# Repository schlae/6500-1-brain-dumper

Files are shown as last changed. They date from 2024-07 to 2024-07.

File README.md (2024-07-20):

# 6500/1 Brain Dumper

Do you have a 6500/1 microcontroller made by MOS, Rockwell, or NCR? (and possibly others)
Do you want to dump the contents of the ROM? Here's a board for you!

This design is derived from work by Jim Brain documented [here](https://e4aws.silverdr.com/hacks/6500_1/)
with design files [here](https://github.com/Project-64/reloaded/tree/master/1520/extraction).

The original design was built on a breadboard. I've turned this into a simple PC board to save
you the effort of wiring it up. Along the way, I ported the code to another MCU (ATmega644) mostly
because that is what I had. I also edited the code to make it slightly more reliable by putting out
more clock cycles while RESET# is held low. (Although it is still not perfect and it usually takes
several tries to get a good dump.)

[Schematic](6500Dumper.pdf)

[Bill of Materials](6500Dumper.csv)

## Fabrication

I have not included the fab files because I haven't fabbed out and tested this board yet. Do this
at your own risk from the KiCad source files.

## Firmware

Build the firmware using the `make` command, assuming you have `avr-gcc` and all that installed.
I like to use the TL866 programmer with the `minipro` Linux software to program the ATmega.

Make sure to set the configuration fuses as follows:

* fuses\_lo = 0xff
* fuses\_hi = 0xd9
* fuses\_ext = 0xfd
* lock = 0xff

## Usage

The device works by putting the 6500/1 into test mode by applying 10V to the RESET# input. It
then bootstraps a small program into the MCU's RAM which copies the contents of the internal
ROM out through an I/O port, which the ATmega can read and route through its serial port to
the host.

After building up the board, connect a serial cable such as FTDI or a [module](https://www.sparkfun.com/products/15096).
Make sure it is configured for 5V operation! On the modules this is a little jumper or
PCB trace you have to cut and solder.

Connect an oscilloscope to the TARGET RESET test point on one channel (set to trigger on the
rising edge) and another channel to the PC1 test point (header pin 2 on J6). This will let
you tell if the 6500/1 has entered test mode and is putting out data.

Connect a 5V bench supply to the +5V and GND test points. Connect an *adjustable* bench supply
to the +10V input and GND. Set the current limit on this supply to something less than 100mA
to help prevent damage the chip under test, just in case.

If this is your first time using the board, you may want to power it up without the 6500/1
in the socket just to verify that the RESET# output behaves correctly. See the waveforms
below.

Put the 6500/1 chip into the J1 socket, and turn on the power. On the oscilloscope, you should
see the RESET# line go up to 10V, then back down to 5V, and you should see a row of pulses
on PC1. If you don't, examine the magnitude of the pulses on PC1 that occur *while RESET# is
at 10V*. Pulses that appear stunted or at around 2.5V mean that there is output contention
and the 6500/1 is not in test mode. 

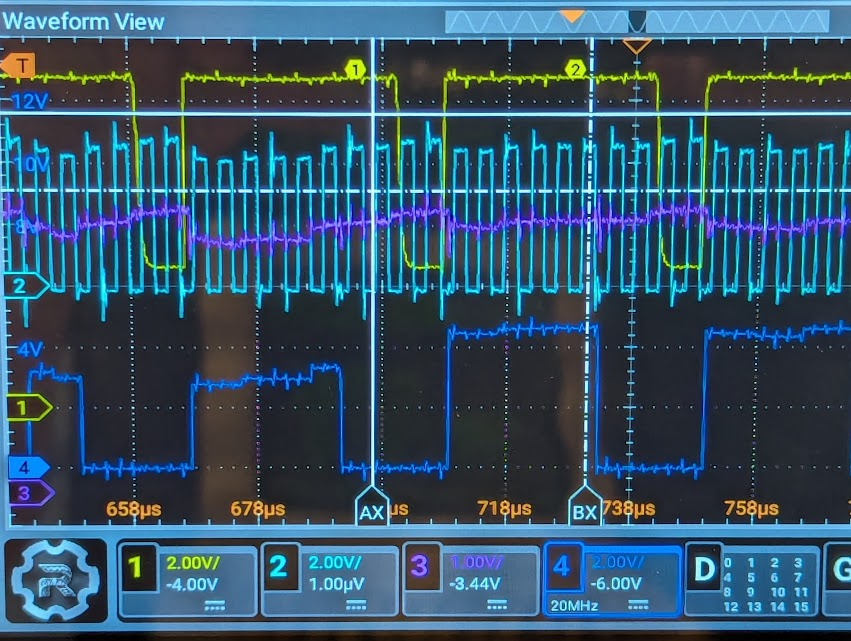
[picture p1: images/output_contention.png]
Scope shot showing output contention on PC1

**Note that CH4 (PC1) has two stunted pulses caused by output contention. CH1=reset and CH2=clock**

You might have to increase the +10V rail (but keep it below
12V or so) and then hit the reset button on the upper left to try again. It may take several tries.

If all goes well, you should see a regular set of pulses on PC1, something like this:

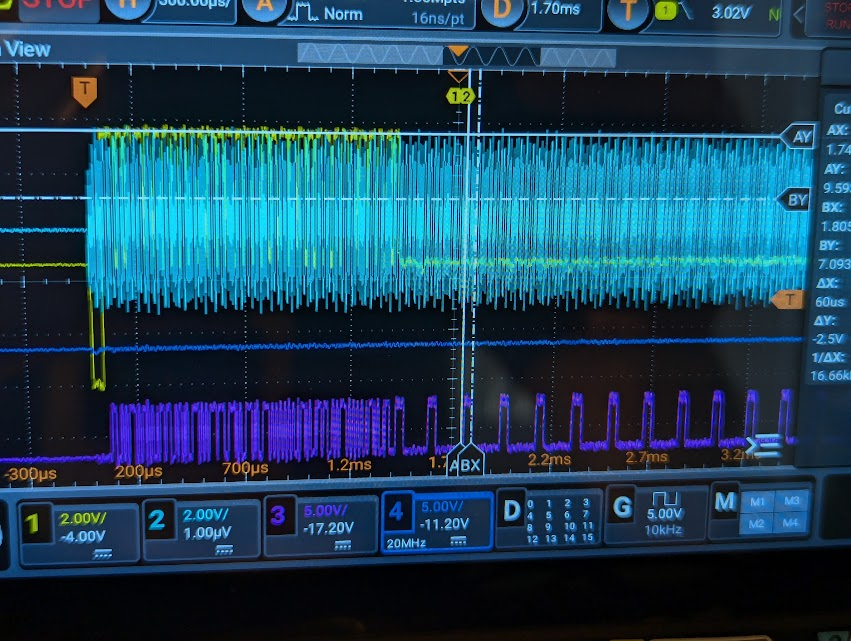
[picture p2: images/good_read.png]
Regular pulses on PC1 when RESET is at 5V, not 10V

**CH4 (PC1) shows regular pulses after RESET# falls to 5V.**

If that is the case, binary data will be transmitted from the ATmega at 57600 baud, 8N1.
This represents the binary data read back from the 6500/1's ROM (located at address
0x800 to 0xfff). I've provided a terrible Python program, `ser_read.py` to save that to
a file. You'll want to edit it to change the filename, serial port, etc (I told you
it's bad!)

## Licensing

This program is free software; you can redistribute it and/or modify
it under the terms of the GNU General Public License as published by
the Free Software Foundation; either version 2 of the License, or
(at your option) any later version.

This program is distributed in the hope that it will be useful,
but WITHOUT ANY WARRANTY; without even the implied warranty of
MERCHANTABILITY or FITNESS FOR A PARTICULAR PURPOSE.  See the
GNU General Public License for more details.

You should have received a copy of the GNU General Public License
along with this program; if not, write to the Free Software
Foundation, Inc., 59 Temple Place, Suite 330, Boston, MA  02111-1307  USA

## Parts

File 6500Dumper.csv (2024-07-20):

Item | Qty | Reference(s) | Value
1 | 2 | C1, C2 | 20pF
2 | 2 | C3, C4 | 0.1uF
3 | 1 | C5 | 10uF
4 | 1 | C6 | DNI
5 | 1 | J1 | 6500/1
6 | 1 | J2 | SERIAL
7 | 1 | J3 | +5V
8 | 1 | J4 | +10V
9 | 2 | J5, J11 | GND
10 | 1 | J6 | SCOPE
11 | 1 | J7 | RESET
12 | 1 | J8 | EN_10V
13 | 1 | J9 | RST_LOW
14 | 1 | J10 | CLOCK
15 | 2 | Q1, Q2 | 2N3904
16 | 1 | Q3 | 2N3906
17 | 2 | R1, R3 | 4.7K
18 | 1 | R2 | 1K
19 | 3 | R4, R5, R7 | 10K
20 | 1 | R6 | 30 Ohm
21 | 1 | SW1 | RESET
22 | 1 | U1 | ATmega644PA-P
23 | 1 | Y1 | 16MHz

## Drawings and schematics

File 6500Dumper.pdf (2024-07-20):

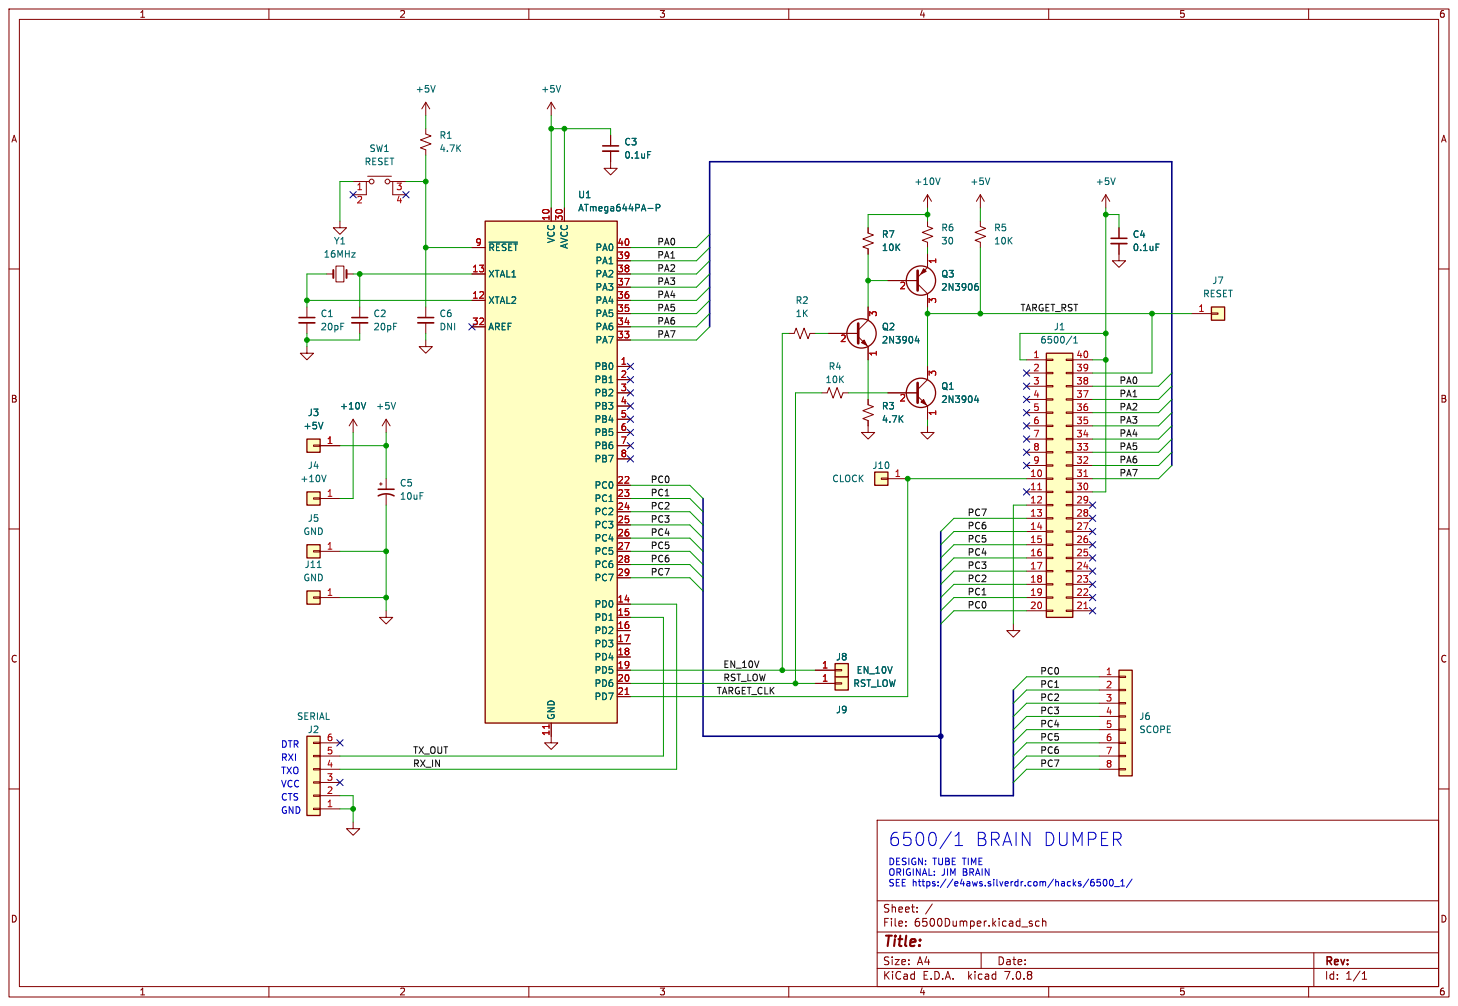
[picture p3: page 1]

Id: 1/1 Title: File: 6500Dumper.kicad_sch Sheet: / 1

SEE https://e4aws.silverdr.com/hacks/6500_1/

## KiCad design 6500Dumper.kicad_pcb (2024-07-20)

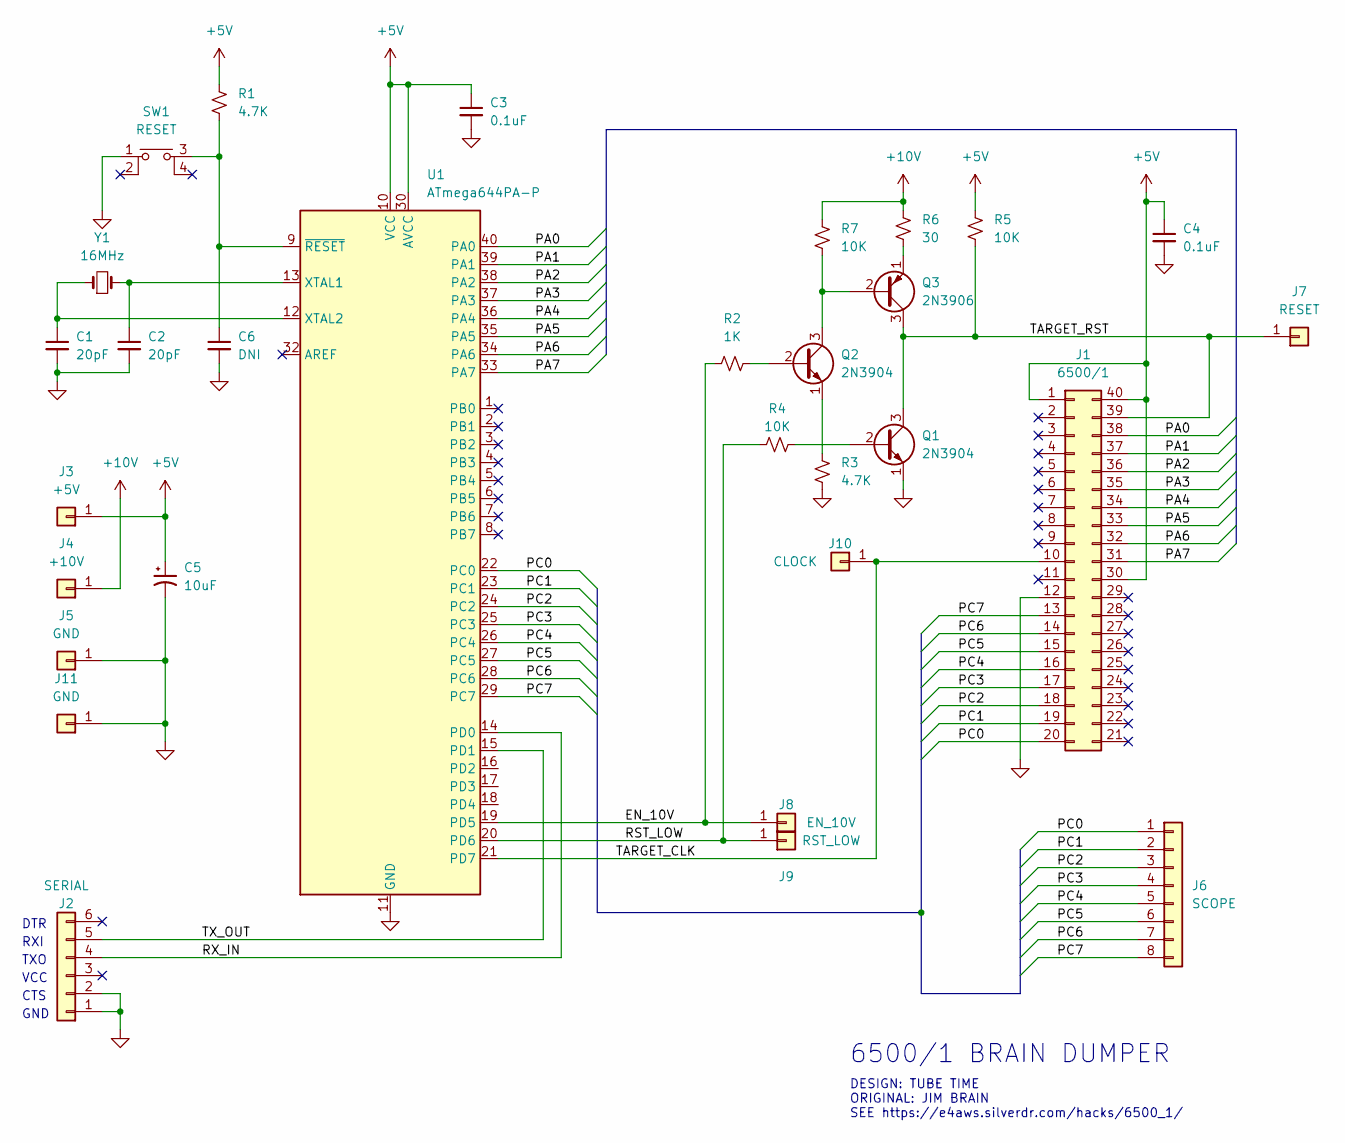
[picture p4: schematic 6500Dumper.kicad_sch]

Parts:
C1, C2: 20pF; C_Disc_D3.0mm_W1.6mm_P2.50mm
C3, C4: 0.1uF; CAPAC200
C5: 10uF; CAPAE200P500X1100
C6: DNI; C_Disc_D3.0mm_W1.6mm_P2.50mm
J1: 6500/1; DIP254P1524X635-40
J2: SERIAL; PinHeader_1x06_P2.54mm_Horizontal
J3: +5V; TP_KEYSTONE_5005_9
J4: +10V; TP_KEYSTONE_5005_9
J5, J11: GND; TP_KEYSTONE_5005_9
J6: SCOPE; PinHeader_1x08_P2.54mm_Vertical
J7: RESET; TP_KEYSTONE_5005_9
J8: EN_10V; TP_KEYSTONE_5005_9
J9: RST_LOW; TP_KEYSTONE_5005_9
J10: CLOCK; TP_KEYSTONE_5005_9
Q1, Q2: 2N3904; TO-92L
Q3: 2N3906; TO-92L
R1, R3: 4.7K; RESA500
R2: 1K; RESA500
R4, R5, R7: 10K; RESA500
R6: 30; RESA500
SW1: RESET; ESWITCH_TL1105
U1: ATmega644PA-P; DIP254P1524X635-40
Y1: 16MHz; Crystal_HC49-U_Vertical

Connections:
+5V: C3.1, C4.1, C5.1, J1.1, J1.30, J1.40, J3.1, R1.1, R5.1, U1.10 (VCC), U1.30 (AVCC)
+10V: J4.1, R6.1, R7.1
/EN_10V: J8.1, R2.1, U1.19 (PD5)
/PA0: J1.38, U1.40 (PA0)
/PA1: J1.37, U1.39 (PA1)
/PA2: J1.36, U1.38 (PA2)
/PA3: J1.35, U1.37 (PA3)
/PA4: J1.34, U1.36 (PA4)
/PA5: J1.33, U1.35 (PA5)
/PA6: J1.32, U1.34 (PA6)
/PA7: J1.31, U1.33 (PA7)
/PC0: J1.20, J6.1, U1.22 (PC0)
/PC1: J1.19, J6.2, U1.23 (PC1)
/PC2: J1.18, J6.3, U1.24 (PC2)
/PC3: J1.17, J6.4, U1.25 (PC3)
/PC4: J1.16, J6.5, U1.26 (PC4)
/PC5: J1.15, J6.6, U1.27 (PC5)
/PC6: J1.14, J6.7, U1.28 (PC6)
/PC7: J1.13, J6.8, U1.29 (PC7)
/RST_LOW: J9.1, R4.1, U1.20 (PD6)
/RX_IN: J2.4, U1.14 (PD0)
/TARGET_CLK: J1.10, J10.1, U1.21 (PD7)
/TARGET_RST: J1.39, J7.1, Q1.3 (C), Q3.3 (C), R5.2
/TX_OUT: J2.5, U1.15 (PD1)
GND: C1.2, C2.2, C3.2, C4.2, C5.2, C6.2, J1.12, J2.1, J2.2, J5.1, J11.1, Q1.1 (E), R3.2, SW1.1, U1.11 (GND), U1.31 (GND)
unnamed: Q1.2 (B), R4.2
unnamed: Q2.2 (B), R2.2
unnamed: Q2.3 (C), Q3.2 (B), R7.2
unnamed: Q2.1 (E), R3.1
unnamed: Q3.1 (E), R6.2
unnamed: C2.1, U1.13 (XTAL1), Y1.2
unnamed: C1.1, U1.12 (XTAL2), Y1.1
unnamed: C6.1, R1.2, SW1.3, U1.9 (~RESET)

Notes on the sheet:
TXO
VCC
DESIGN: TUBE TIME ORIGINAL: JIM BRAIN SEE https://e4aws.silverdr.com/hacks/6500_1/
6500/1 BRAIN DUMPER
GND
CTS
DTR
RXI

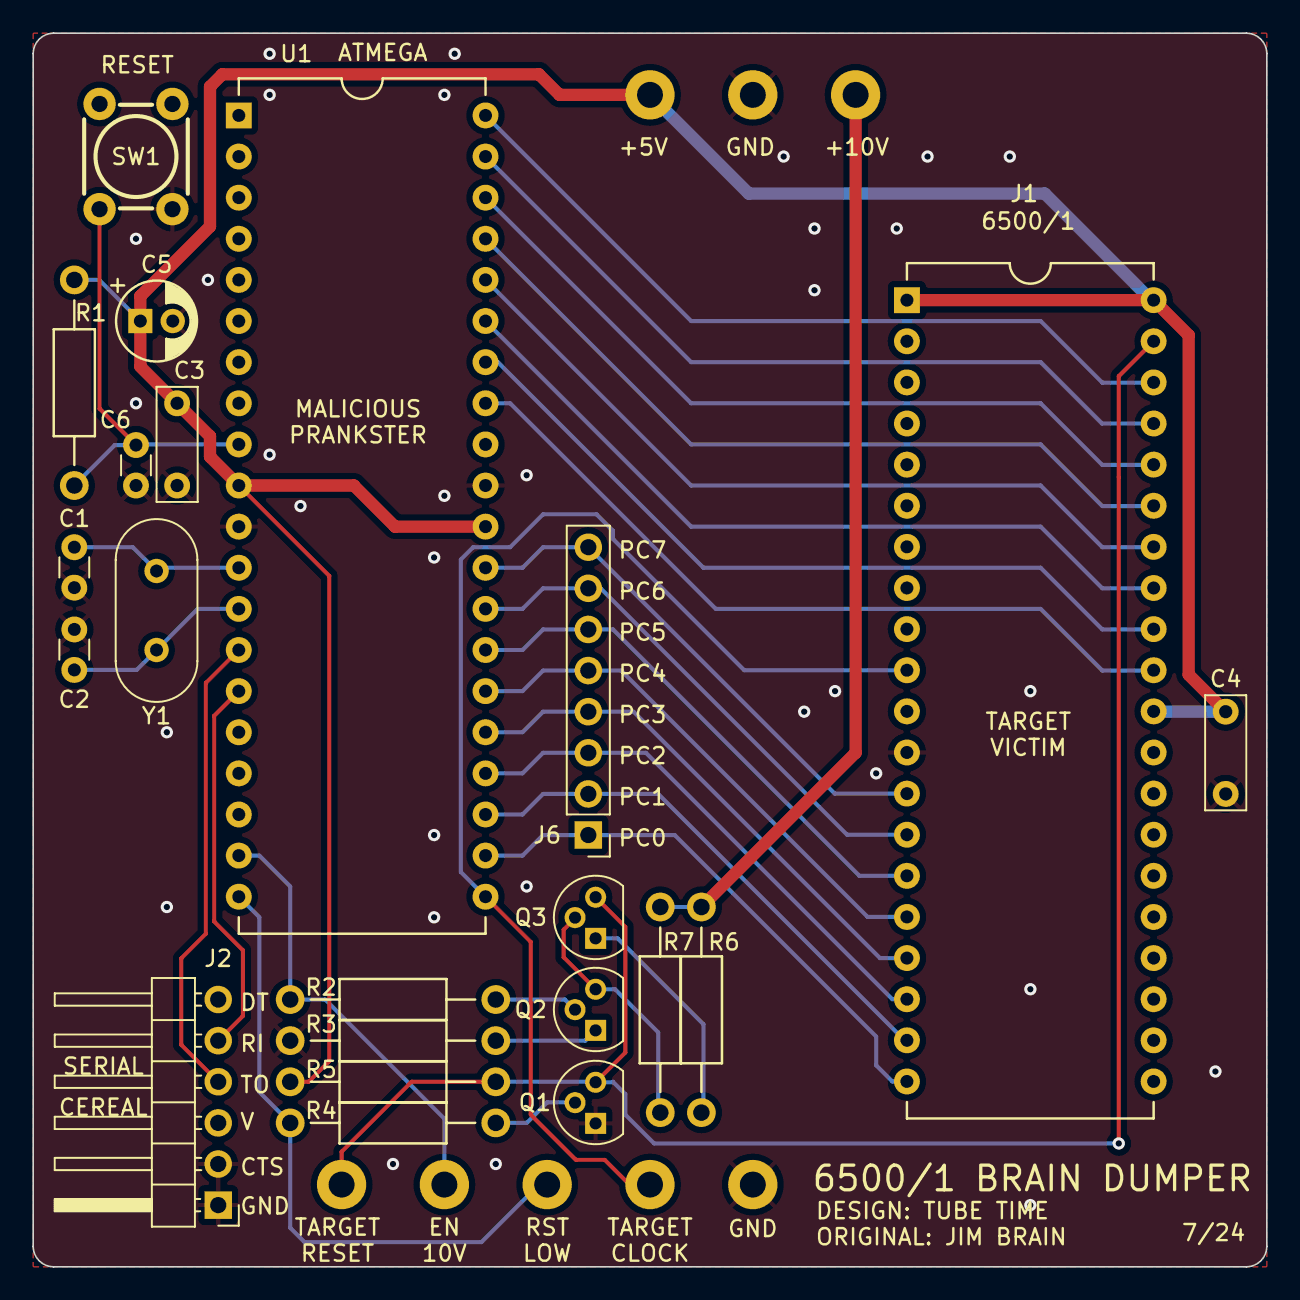
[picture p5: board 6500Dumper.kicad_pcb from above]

Board: 2 copper layers, 76.2 x 76.2 mm, 30 parts (0 on the bottom side), 33 nets.

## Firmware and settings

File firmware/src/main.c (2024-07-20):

/*
    6500Dump - AVR code to dump MOS 6500 ROM contents
    Copyright Jim Brain 2014

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
    Notes:

    There are two versions of code in this file:

    Version #1 (the original working code)

    The code takes a brute force approach to pulling memory contents from the
    6500/1.  Based on a plan by Greg King to simply pull data directly from
    the ROM, with no need to create a program that runs in the 6500/1, the
    code holds RESET low for a suitable time, puts the CPU into TEST mode, and
    tries to synchronize the opcode stream using a set of opcodes provided by
    Gerrit Heitsch, modified based on empirical testing.  Once synchronization
    happens, it instructs the internal CPU to load one memory location into the
    .A register, dropping out of TEST during the cycle when the load from ROM
    occurs. It then stores the data to PORTA, JAMS the CPU, and the AVR reads
    the data from PORTA, sends it out via the AVR UART, and then repeats the
    process for the next memory location. The code does not always synchronize,
    so a few resets of the AVR MEGA32 are sometimes required.  Also, though I
    tried setting up the code to read multiple pages of memory in one run, that
    pushed the code out of synchronization, so you must recompile and
    re-download the code into the AVR for each page.

    Truly, this is truly a hack of a codebase.  It was a
    quick (and evidently successful) attempt to dump ROM contents.  The code is
    brittle, in that there's still much we do not know about startup timing
    and synchronization.  As well, the 16MHz AVR seems just barely capable of
    keeping things in sync at that speed.  I tried to implement the send_data
    as part of an OCR ISR triggered on clock state change, but the overhead
    was too much.  Thus, the horrid busy-wait loops.  I expect most robust
    implementation would be to rewrite into AVR ASM, simply count cycles,
    and manually drive the clock signal changes.

    The number of NOP instructions is truly overkill.  I added them until I
    found a reasonably stable setup.

    Also, the uart data send has no failsafe.  I rely on the fact that the
    reset + code execution path on the 6500/1 takes enough time to send at
    least one byte at 57600

    You can define "IMMEDIATE" in the codebase to test out immediate mode.

    Version #2 (proving that the original description in the 6500/1 datasheet 
    is also workable)

    The code stuffs a small program into the first few RAM locations that
    increments through each ROM address, reading the value in ROM and then 
    storing on PORTA.  It also strobes PORTC to signal that a new piece
    of data is valid.  As with the rest of the code herein, I am sure there
    are lots of more elegant ways to write this little program, but I was 
    more interested in getting it running, so it morphed from reading a single
    location into reading a 256 byte range and then reading the entire 2kB
    ROM.  I also was able to reduce the "startup" code to a bare minimum, which
    suggests that the 6502 needs 4 cycles to start executing code.  This code is
    much less brittle than the original attempt, so I would use it to read ROM
    contents.  

    The AVR resets the 6500/1 for 4 cycles, then lets it run for 4 cycles before
    sending code to store the program into RAM.  It then sets up a JuMP to $0000
    and turns off TEST mode, allowing the 6502 to run code from RAM, and the 6502
    code then reads data and delivers it to the PORTA, where the AVR picks it
    up after seeing the STROBE signal.  The received data is then sent to the UART.

*/

#include <inttypes.h>
#include <avr/io.h>
#include <util/atomic.h>
#include <util/delay.h>

static uint8_t i = 255;

#define F_CPU 16000000
#define UART0_BAUDRATE 57600

#define CALC_BPS(x) (int)((double)F_CPU/(16.0*x)-1)
#define RESET _BV(PD6)
#define TEST _BV(PD5)
#define CLK _BV(PD7)

#define RESET_OFF()  PORTD &= ~RESET
#define RESET_ON()  PORTD = (PORTD & ~TEST) | RESET
#define TEST_ON()   PORTD = (PORTD & ~RESET) | TEST
#define TEST_OFF()  PORTD &= ~TEST

static inline __attribute__((always_inline)) void send_data(uint8_t data) {
  PORTC = data;

  while(!(TIFR2 & _BV(OCF2A))); // went high
  TIFR2 |= _BV(OCF2A);
  while(!(TIFR2 & _BV(OCF2A))); // went lo
  TIFR2 |= _BV(OCF2A);
  while(!(TIFR2 & _BV(OCF2A))); // went hi
  TIFR2 |= _BV(OCF2A);
  while(!(TIFR2 & _BV(OCF2A))); // went lo
  TIFR2 |= _BV(OCF2A);
}

#define VER2
#ifdef VER2
int main(void) {
  UCSR0C = _BV(UCSZ01) | _BV(UCSZ00);
  UBRR0H = CALC_BPS(UART0_BAUDRATE) >> 8;
  UBRR0L = CALC_BPS(UART0_BAUDRATE) & 0xff;
  UCSR0B = (_BV(TXEN0));
  uint8_t code[] = { 0xA9 ,0x00       // lda #0
                    ,0x85 ,0x82       // sta $82
                    ,0xA2 ,0x00       // ldx #0
                    ,0xBD ,0x00 ,0x08 //lda $800,x
                    ,0x85 ,0x80       // sta $80 store data to PORTA
                    ,0xA9 ,0xFF       // lda #$ff PORTC=ff
                    ,0x85 ,0x82       // sta $82
                    ,0xA9 ,0x00       // lda #00 PORTC=00
                    ,0x85 ,0x82       // sta $82
                    ,0xE8             // inx
                    ,0xD0 ,0xF0       // bne loop
                    ,0xe6 ,0x08       // inc $08
                    ,0xa5, 0x08       // lda $08 modify start address
                    ,0xc9, 0x10       // cmp $10
                    ,0xd0 ,0xE6       // bne loop2
                    ,0xf0, 0xfe       // beq loop3 (this);
                   };


  DDRD = CLK | TEST | RESET;
  DDRC = 0xff;
  RESET_ON();
  DDRA = 0;
  PORTA = 0xff;
  OCR2A = 32;
  TCCR2A = _BV(WGM21) | _BV(COM2A0);
  TCCR2B = _BV(CS20); // /16MHz, CTC mode

  while(1) {
    RESET_ON();
    send_data(0xEA);
    send_data(0xEA);  // it'll work without the remaining 3 of these, but it's better with all 4
    send_data(0xEA);
    send_data(0xEA);
    send_data(0xEA);
    send_data(0xEA);
    send_data(0xEA);
    send_data(0xEA);


    TEST_ON();

    send_data(0xEA);
    send_data(0xEA);

    send_data(0xEA);
    send_data(0xEA);

    for(i = 0; i< sizeof(code);i++) {
      send_data(0xA9);
      send_data(code[i]);
      send_data(0x85);
      send_data(0x00 + i);
      TEST_OFF();
      send_data(0);  // extra cycle
      TEST_ON();
    }
    send_data(0x4c);
    send_data(0);
    send_data(0);
    TEST_OFF();
    PORTC = 0;
    DDRC = 0;
    //while(PINC);
    while(1) {
      while(!PINC);
      UDR0 = PINA;  // uart output
      while(PINC);
    }
  }
}
#else
int main(void) {
  UCSRC = _BV(URSEL) | _BV(UCSZ1) | _BV(UCSZ0);
  UBRRH = CALC_BPS(UART0_BAUDRATE) >> 8;
  UBRRL = CALC_BPS(UART0_BAUDRATE) & 0xff;
  UCSRB = (_BV(TXEN));


  DDRD = CLK | TEST | RESET;
  DDRC = 0xff;
  RESET_ON();
  DDRA = 0;
  PORTA = 0xff;
  OCR2 = 32;
  TCCR2 = _BV(WGM21) | _BV(COM20) | _BV(CS20); // /16MHz, CTC mode

  while(1) {
    send_data(0xEA); // just wasting some time...
    RESET_ON();
    send_data(0xEA);
    i++;
    send_data(0xEA);
    send_data(0xEA);

    send_data(0xEA);
    send_data(0xEA);
    send_data(0xEA);
    send_data(0xEA);

    send_data(0xEA);
    send_data(0xEA);
    send_data(0xEA);
    send_data(0xEA);

    send_data(0xEA);
    send_data(0xEA);
    send_data(0xEA);
    send_data(0xEA);

    send_data(0xEA);
    send_data(0xEA);
    send_data(0xEA);
    send_data(0xEA);
    TEST_ON();

    send_data(0xEA);  // these 4 can be removed and the code still
    send_data(0xEA);  // seems to work most of the time.
    send_data(0xEA);
    send_data(0xEA);

    send_data(0xEA); // but, these seem to be needed.
    send_data(0xEA); //keep
    send_data(0xEA); //keep

    send_data(0x2C);
    send_data(0x24);
    send_data(0xEA);
    send_data(0xEA);
    send_data(0x78);
    send_data(0x78);
//#define IMMEDIATE
#ifdef IMMEDIATE
    send_data(0xA9);
    send_data(i);
#else
    send_data(0xad);
    send_data(i);
    send_data(0xff);
    TEST_OFF();
    send_data(0);
    TEST_ON();

#endif
    send_data(0x85);
    send_data(0x80);

    send_data(0x80);
    //send_data(0x02);
    UDR = PINA;  // uart output
  }
}
#endif
